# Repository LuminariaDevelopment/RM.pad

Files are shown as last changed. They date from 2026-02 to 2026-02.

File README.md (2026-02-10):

# RM.pad
A mechanical macropad designed for productivity and musical expression with a minimalistic and clean design.

## Features
* Three Layers: Productivity, System/Media, and a bonus mini MIDI Instrument.
* Layer-Specific Lighting: Visual feedback that changes depening on which layer you are currently using.
* Multi-Function Rotary Encoder: Context-aware knob for volume, scrolling, and MIDI CC.
  




## Usage

The RM.pad uses a layer system. Navigation and feedback are handled via the bottom-left key and the integrated NeoPixels.

### Layer Navigation
* **Switching Layers:** Press the bottom-left key to cycle through modes!
* **Visual Indicators:**
    * Deep Blue: Layer 0 (Productivity focused)
    * Sky Blue: Layer 1 (System focused)
    * White: Layer 2 (MIDI)

### Layer 0: Productivity (Deep Blue)
Designed for Windows OS and browser navigation.
* **Top Row:** Open Run Command (Win+R), New Tab (Ctrl+T), Focus Address Bar (Ctrl+L).
* **Middle Row:** Show Desktop (Win+D), Close Window (Alt+F4), Maximize Window (Win+Up).
* **Bottom Row:** Cycle Layer, Text Macro (Pre-defined sentence), Lock PC (Win+L).
* **Encoder:** Rotate for Volume Up/Down; Press to Mute.

### Layer 1: System and Media (Sky Blue)
Designed for media playback and hardware settings.
* **Top Row:** Play/Pause, Next Track, Previous Track.
* **Middle Row:** Toggle RGB Power, Cycle RGB Animations, Reset to Static Sky Blue.
* **Bottom Row:** Cycle Layer, No Command (for now), Reset Microcontroller.
* **Encoder:** Rotate for Page Up/Down; Press for Home key.

### Layer 2: MIDI Keyboard (White)
Turns the macropad into a musical instrument for DAWs or web synths.
* **Keypad:** 8 keys mapped to the C-Major scale (C, D, E, F, G, A, B, C).
* **Bottom-Left Key:** Cycles back to Layer 0.
* **Encoder:** Rotate to send MIDI CC (Continuous Controller) data for like volume or filter cutoff.

### MIDI Integration
To use the MIDI layer, simply open your Digital Audio Workstation (DAW) and select "KMK MIDI" as the active MIDI Input device.

# Bill Of Materials

XIAO RP2040 Microcontroller - [here](https://www.amazon.in/Microcontroller-Dual-Core-MicroPython-CircuitPython-Interfaces/dp/B09NNVNW7M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) (x1)

1N4148 / Diodes - [here](https://www.digikey.com/en/products/detail/onsemi/1N4148/458603) (x9)

Cherry MX Keys - [here](https://www.amazon.in/dp/B09ZT8BY6W/ref=twister_B0BFGC2MJY?_encoding=UTF8) (x9)

SK6812 Mini - [here](https://keeb.io/products/sk-6812-mini-e-rgb-leds-12-pack) (x3)

EC11 Rotary Encoder - [here](https://keeb.io/products/rotary-encoder-ec11) (x1)

1.7mm(diameter)x10mm screws (x4)  - [here](https://www.moddiy.com/products/M1.7-x-10mm-Black-Screws-(PM1.7X10).html)

Blank DSA Keycaps (Black)(x9) - [here](https://meckeys.com/shop/accessories/keyboard-accessories/keycaps/blank-dsa-keycaps-1u/)

(AI was used to polish `README.md` for better readability)

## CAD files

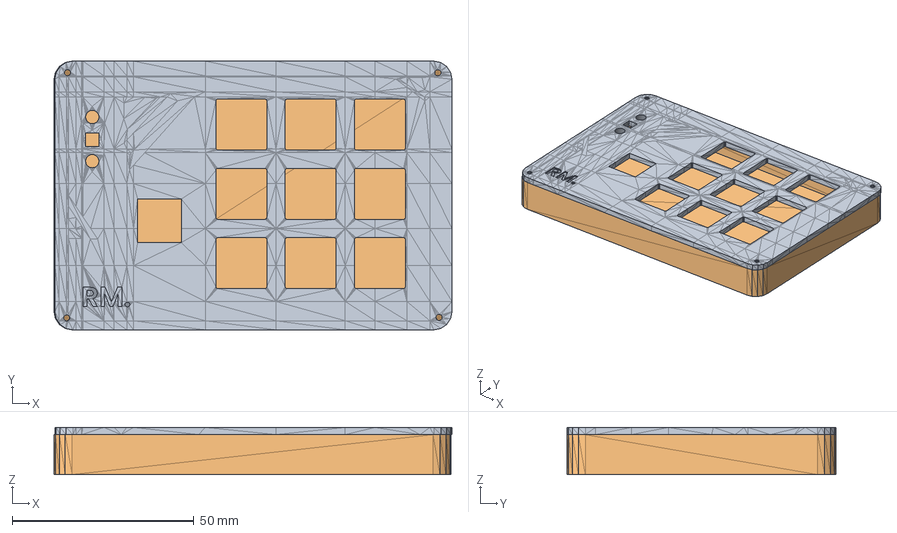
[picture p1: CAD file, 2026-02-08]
CAD/RM.pad - Full.step
109.5 x 73.9 x 13.0 mm

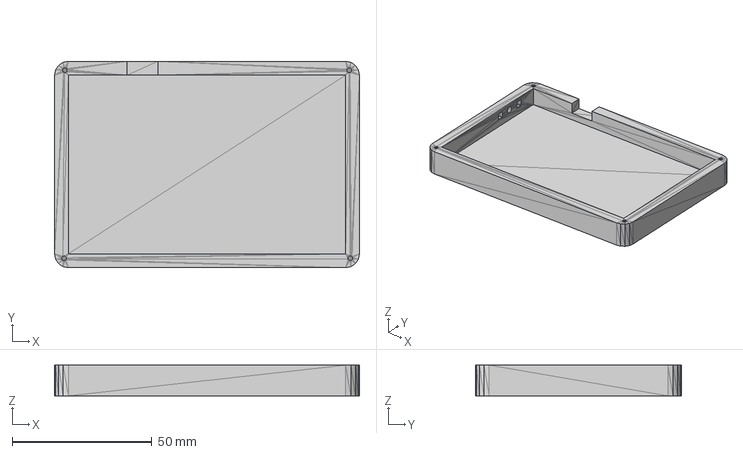
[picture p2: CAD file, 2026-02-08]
CAD/RM.pad - Bottom.step
109.2 x 73.9 x 11.0 mm

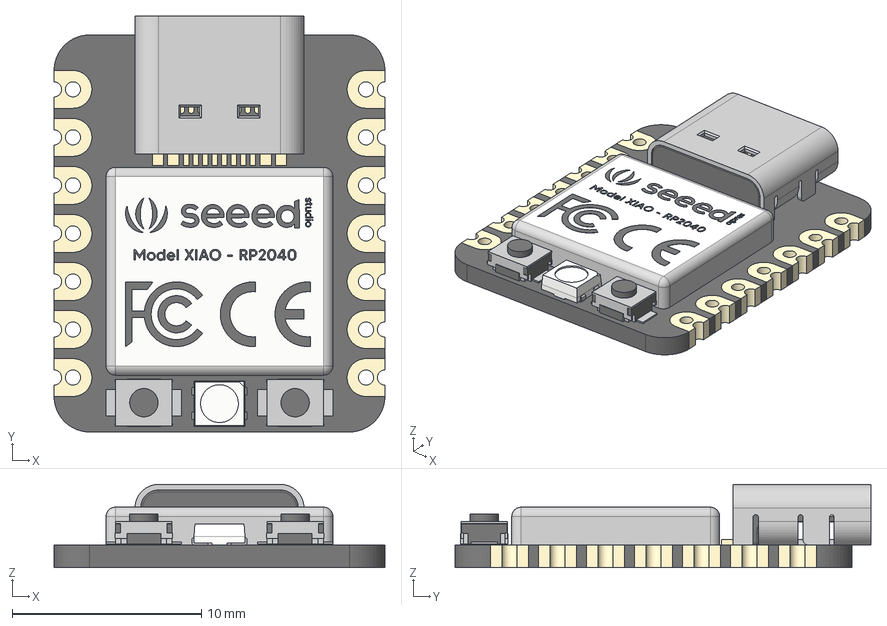
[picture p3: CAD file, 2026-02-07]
PCB/RMpad/assets/3D/seed.step
17.5 x 22.0 x 4.40 mm
type-c v2
smd_button v3
DOUT
DIN
VSS
VDD
smd_button v3(Mirror)

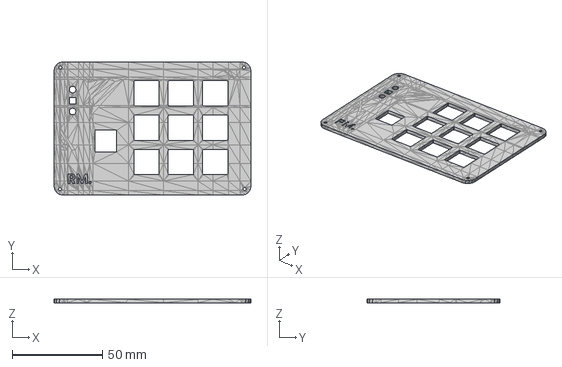
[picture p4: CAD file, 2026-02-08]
CAD/RM.pad - Top.step
109.2 x 73.9 x 2.00 mm

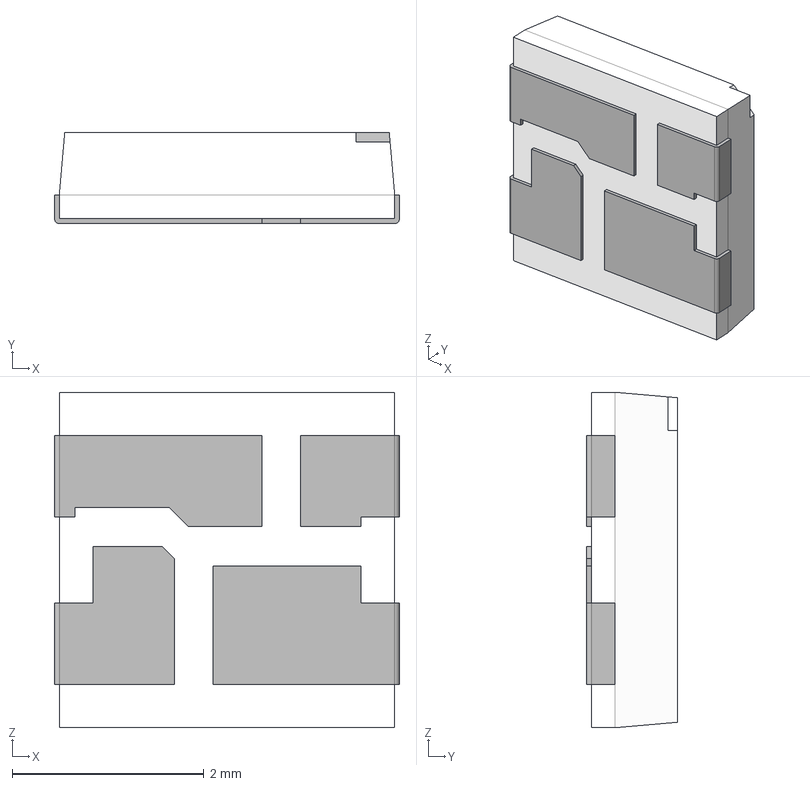
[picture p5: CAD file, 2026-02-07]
PCB/RMpad/assets/3D/SK6812_Mini.step
3.60 x 0.95 x 3.50 mm
SK6812_Mini
SK6812_Mini004
SK6812_Mini003
SK6812_Mini005
SK6812_Mini002
SK6812_Mini001

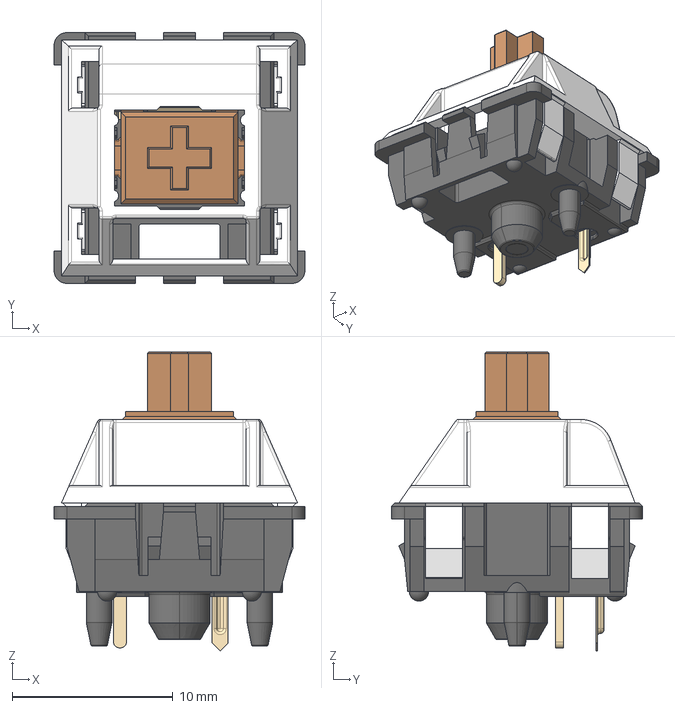
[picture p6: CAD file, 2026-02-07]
PCB/RMpad/assets/3D/SW_Cherry_MX_PCB.stp
15.6 x 15.6 x 18.6 mm

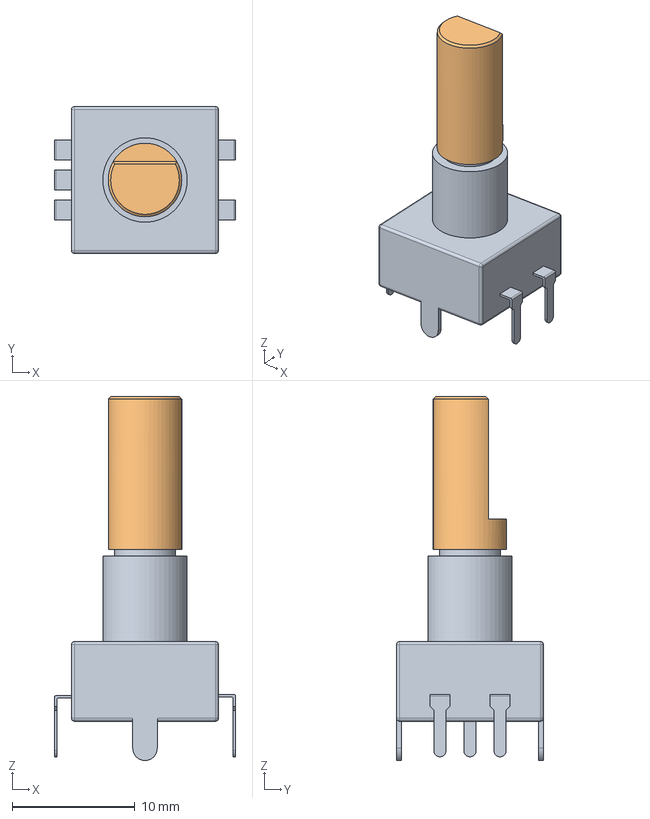
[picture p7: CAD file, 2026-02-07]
PCB/RMpad/assets/3D/RotaryEncoder_Alps_EC11E-Switch_Vertical_H20mm.step
14.8 x 12.0 x 29.7 mm

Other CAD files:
production/RMpad-bottom.stl
production/RMpad-top.stl

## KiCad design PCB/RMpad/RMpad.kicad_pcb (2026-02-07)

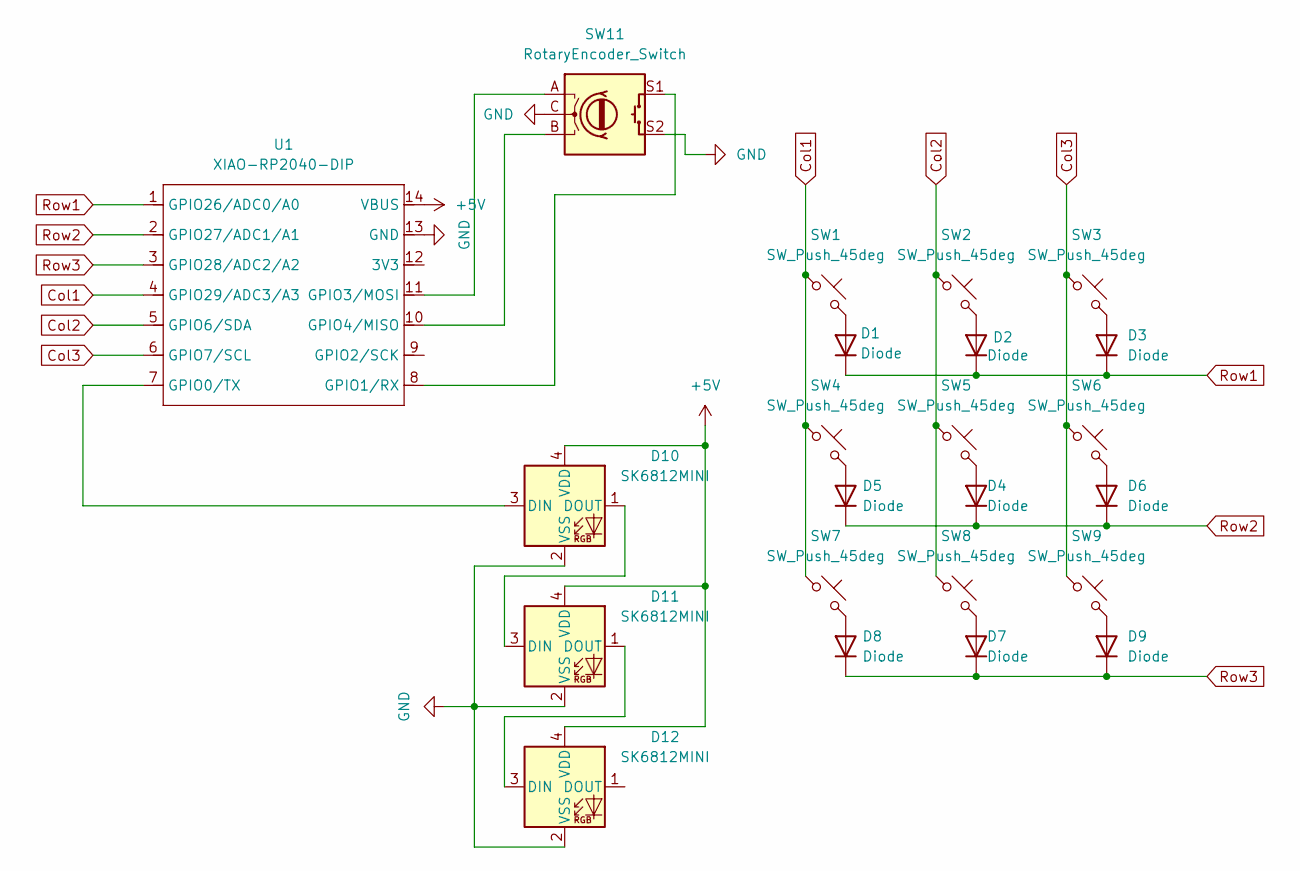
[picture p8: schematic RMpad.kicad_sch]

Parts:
D1, D2, D3, D4, D5, D6, D7, D8, D9: Diode; Diode_DO-35
D10, D11, D12: SK6812MINI; LED_SK6812MINI_PLCC4_3.5x3.5mm_P1.75mm
SW1, SW2, SW3, SW4, SW5, SW6, SW7, SW8, SW9: SW_Push_45deg; SW_Cherry_MX_1.00u_PCB
SW11: RotaryEncoder_Switch; RotaryEncoder_Alps_EC11E-Switch_Vertical_H20mm_CircularMoun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
U1: XIAO-RP2040-DIP

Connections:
+5V: D10.4 (VDD), D11.4 (VDD), D12.4 (VDD), U1.14 (VBUS)
Col1: SW1.1, SW4.1, SW7.1, U1.4 (GPIO29/ADC3/A3)
Col2: SW2.1, SW5.1, SW8.1, U1.5 (GPIO6/SDA)
Col3: SW3.1, SW6.1, SW9.1, U1.6 (GPIO7/SCL)
GND: D10.2 (VSS), D11.2 (VSS), D12.2 (VSS), SW11.C, SW11.S2, U1.13 (GND)
unnamed: D1.2 (A), SW1.2
unnamed: D2.2 (A), SW2.2
unnamed: D3.2 (A), SW3.2
unnamed: D4.2 (A), SW4.2
unnamed: D5.2 (A), SW5.2
unnamed: D6.2 (A), SW6.2
unnamed: D7.2 (A), SW7.2
unnamed: D8.2 (A), SW8.2
unnamed: D9.2 (A), SW9.2
unnamed: D10.3 (DIN), U1.7 (GPIO0/TX)
unnamed: D10.1 (DOUT), D11.3 (DIN)
unnamed: D11.1 (DOUT), D12.3 (DIN)
unnamed: SW11.S1, U1.8 (GPIO1/RX)
unnamed: SW11.A, U1.11 (GPIO3/MOSI)
unnamed: SW11.B, U1.10 (GPIO4/MISO)
Row1: D1.1 (K), D2.1 (K), D3.1 (K), U1.1 (GPIO26/ADC0/A0)
Row2: D4.1 (K), D5.1 (K), D6.1 (K), U1.2 (GPIO27/ADC1/A1)
Row3: D7.1 (K), D8.1 (K), D9.1 (K), U1.3 (GPIO28/ADC2/A2)

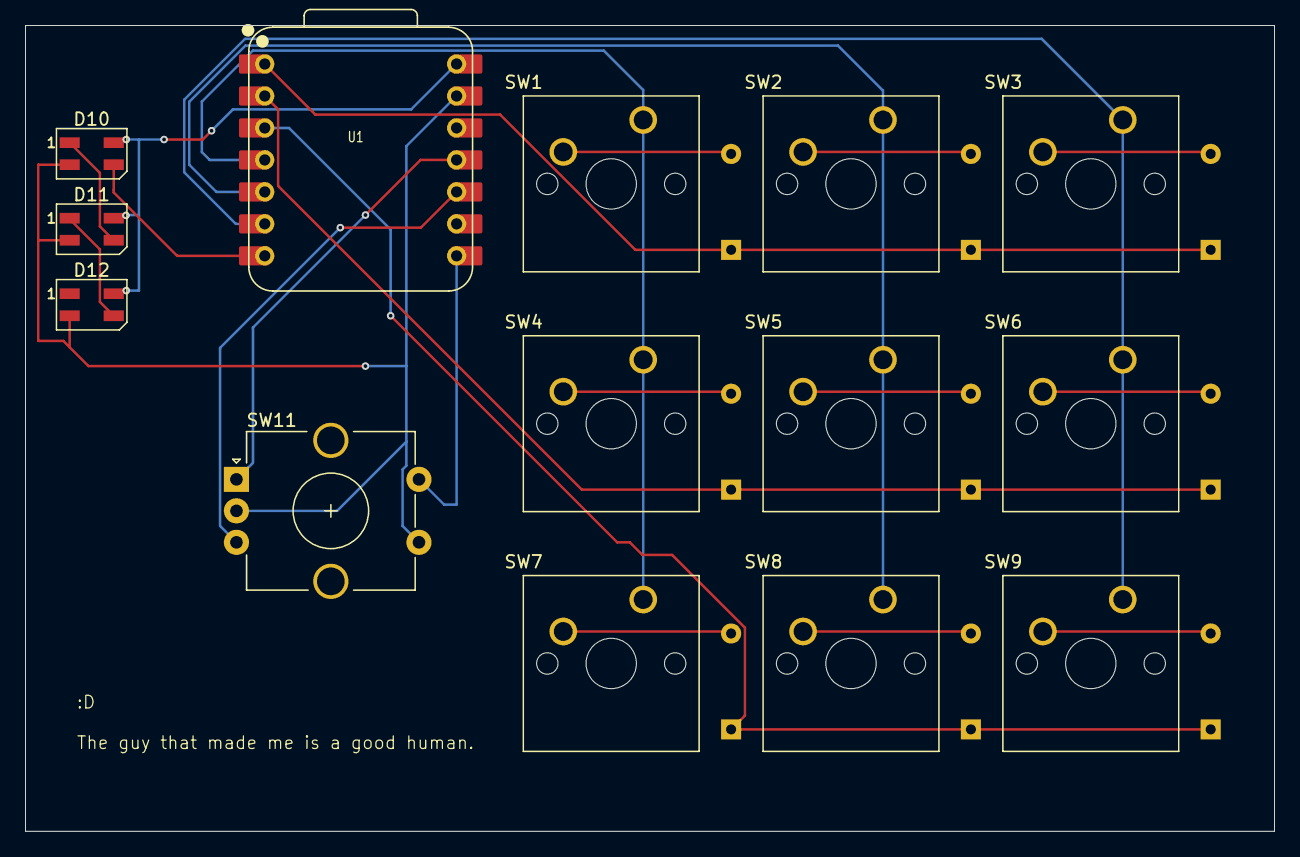
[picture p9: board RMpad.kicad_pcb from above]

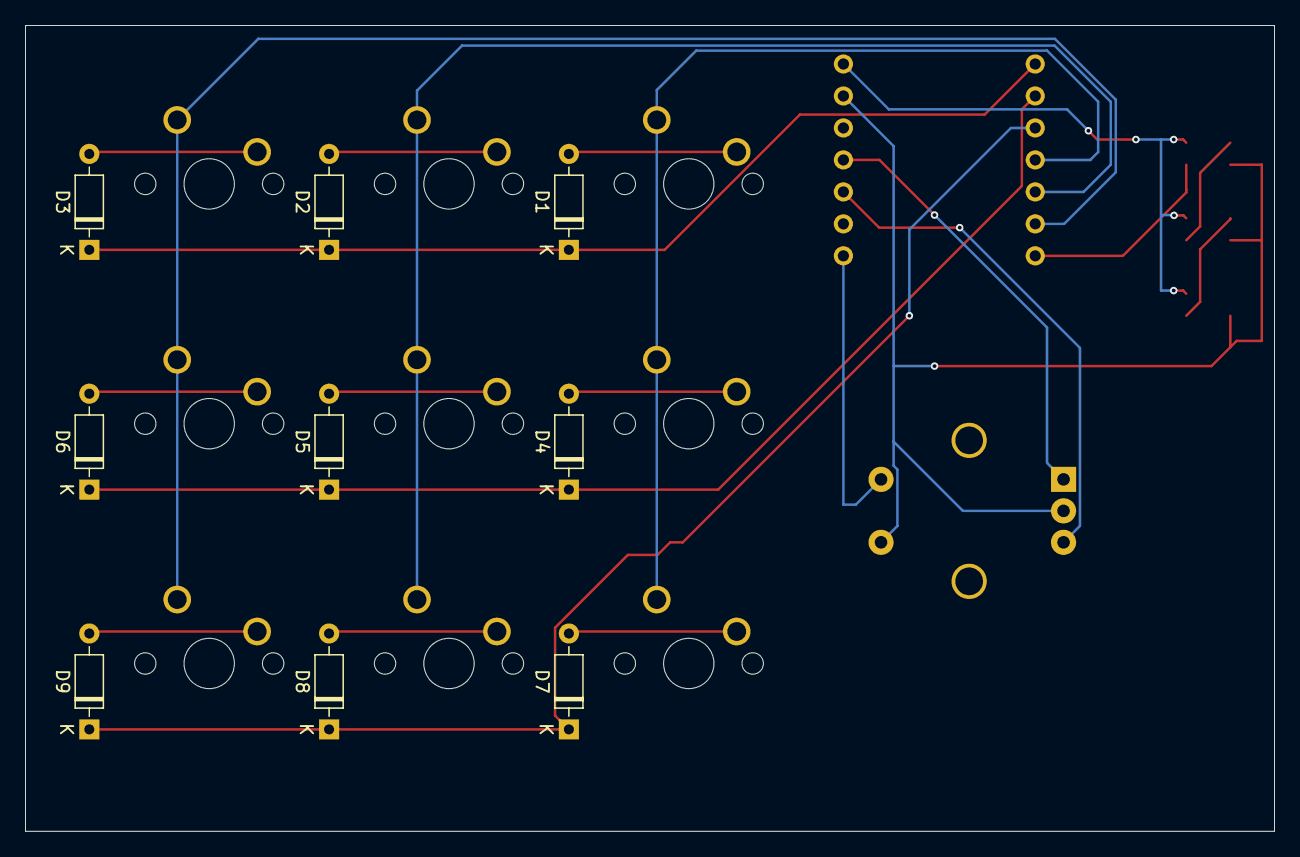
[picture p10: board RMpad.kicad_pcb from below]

Board: 2 copper layers, 99.2 x 64.0 mm, 23 parts (9 on the bottom side), 23 nets.

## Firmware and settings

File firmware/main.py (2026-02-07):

import board
from kmk.kmk_keyboard import KMKKeyboard
from kmk.keys import KC
from kmk.scanners import DiodeOrientation
from kmk.extensions.media_keys import MediaKeys
from kmk.modules.macros import Macros
from kmk.modules.layers import Layers
from kmk.modules.encoder import RotaryEncoder
from kmk.extensions.RGB import RGB
from kmk.extensions.midi import Midi

keyboard = KMKKeyboard()
keyboard.row_pins = (board.GP26, board.GP27, board.GP28)
keyboard.col_pins = (board.GP29, board.GP06, board.GP07)
keyboard.diode_orientation = DiodeOrientation.COL2ROW

layers = Layers()
macros = Macros()
media = MediaKeys()
midi = Midi()
keyboard.modules.append(layers)
keyboard.modules.append(macros)
keyboard.extensions.append(media)
keyboard.extensions.append(midi)

rgb = RGB(
    pixel_pin=board.GP0,
    num_pixels=3,
    val_default=150,
)
keyboard.extensions.append(rgb)

DEEP_BLUE = (0, 119, 255)
SKY_BLUE = (152, 216, 255)
WHITE = (255, 255, 255)

encoder = RotaryEncoder()
encoder.pins = ((board.GP03, board.GP04, None, False),)
encoder.map = (
    ((KC.VOLU, KC.VOLD, KC.MUTE),),
    ((KC.PGUP, KC.PGDN, KC.HOME),),
    ((KC.MIDI_CC(1), KC.MIDI_CC(2), KC.NO),),
)
keyboard.modules.append(encoder)

class LayerColorKey:
    def __init__(self):
        self.current_layer = 0
    
    def toggle(self, *args):
        self.current_layer = (self.current_layer + 1) % 3
        if self.current_layer == 0:
            rgb.set_rgb_fill(DEEP_BLUE)
            keyboard.active_layers = [0]
        elif self.current_layer == 1:
            rgb.set_rgb_fill(SKY_BLUE)
            keyboard.active_layers = [1]
        else:
            rgb.set_rgb_fill(WHITE)
            keyboard.active_layers = [2]

lc_key = LayerColorKey()

keyboard.keymap = [
    [
        KC.LWIN(KC.R), KC.LCTRL(KC.T), KC.LCTRL(KC.L),
        KC.LWIN(KC.D), KC.LALT(KC.F4), KC.LWIN(KC.UP),
        KC.ANY(lc_key.toggle), KC.MACRO("ggs"), KC.LWIN(KC.L),
    ],
    [
        KC.MEDIA_PLAY_PAUSE, KC.MEDIA_NEXT, KC.MEDIA_PREV,
        KC.RGB_TOG, KC.RGB_ANI, KC.RGB_MODE_PLAIN,
        KC.ANY(lc_key.toggle), KC.NO, KC.RESET,
    ],
    [
        KC.MIDI_NOTE(60), KC.MIDI_NOTE(62), KC.MIDI_NOTE(64),
        KC.MIDI_NOTE(65), KC.MIDI_NOTE(67), KC.MIDI_NOTE(69),
        KC.ANY(lc_key.toggle), KC.MIDI_NOTE(71), KC.MIDI_NOTE(72),
    ]
]

if __name__ == '__main__':
    rgb.set_rgb_fill(DEEP_BLUE)
    keyboard.go()

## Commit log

2026-02-07 pcb export and main.py
    [RMpad-B_Cu.gbr, RMpad-B_Mask.gbr, RMpad-B_Paste.gbr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]
2026-02-07 stl exports
    [RMpad-bottom.stl, RMpad-top.stl]
2026-02-08 step export
    [RM.pad - Bottom.step, RM.pad - Full.step, RM.pad - Top.step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]
2026-02-10 gerber zipping
    [RMpad-B_Cu.gbr, RMpad-B_Mask.gbr, RMpad-B_Paste.gbr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]
